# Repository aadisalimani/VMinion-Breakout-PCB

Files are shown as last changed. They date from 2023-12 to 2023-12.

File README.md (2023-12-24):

# VMinion Breakout PCB

This project is focused on creating a PCB that simplifies connections on the Ratrig VMinion. Although designed be me, it is inspired by the divider PCB mod by Vector3D [here](https://github.com/AdamV3D/RR-V-Minion-Mods/tree/main/V3D%20Divider%20PCB). 

## :warning: Beta Version :warning:
Please note that the "VMinion Breakout PCB" is currently in a **beta phase**. It's constantly being updated and improved. Use this mod at your own risk. The rest of the parts (printed casing, mounting parts, etc.) will come soon.

## Open Source
Everything related to this project will be open-source. Contributions, suggestions, and improvements are always welcome.

## Bill of Materials (BOM)
A work-in-progress BOM is available [here](https://docs.google.com/spreadsheets/d/1l2unTY74QwLAbzYWbJA4JIBaFDDriVfRlH6mz4mGnKs/edit?usp=sharing).

## Getting Started
*Features*

Unlike other breakout boards, this has a plethora of ports to fit almost any configuration:

- 4x Motor Ports
- 5x General Ports (Endstop, Servo, Neopixel etc.)
- 1x Probe Port (5v or 24v with diode)
- 3x Fan Ports (Selectable Voltage) - Two Ports Share Selected Voltage
- 1x ADXL Port
- 2x Therm Ports
- 1x Hotend Port (Max ~120W)
- 1x Bed Port (Max ~180W)
- 1x 24v Step Down To 12v (K78L12-500R3)

Uses 2x 2x9 Microfit And 1x Plugable Terminal Block

*Instrucions will follow soon*

## PCB Images
Top
Bottom

## License
This PCB project is licensed under the Creative Commons Attribution-NonCommercial 4.0 International License - see the [LICENSE](LICENSE) file for details.

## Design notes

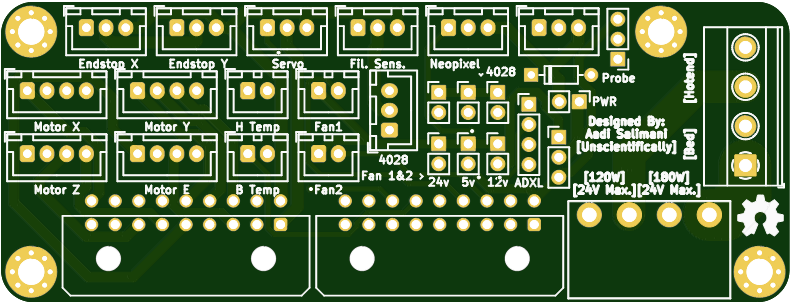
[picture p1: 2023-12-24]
Images/Top.png

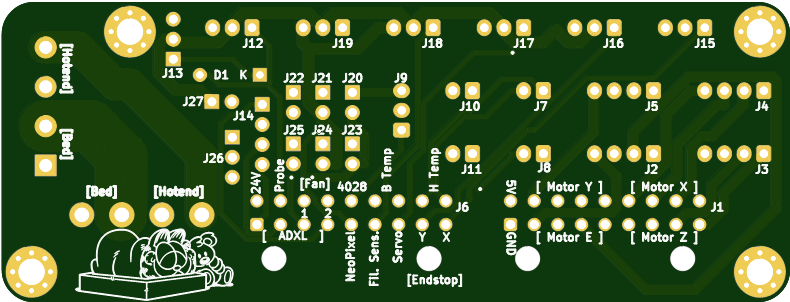
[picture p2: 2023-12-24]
Images/Bottom.png

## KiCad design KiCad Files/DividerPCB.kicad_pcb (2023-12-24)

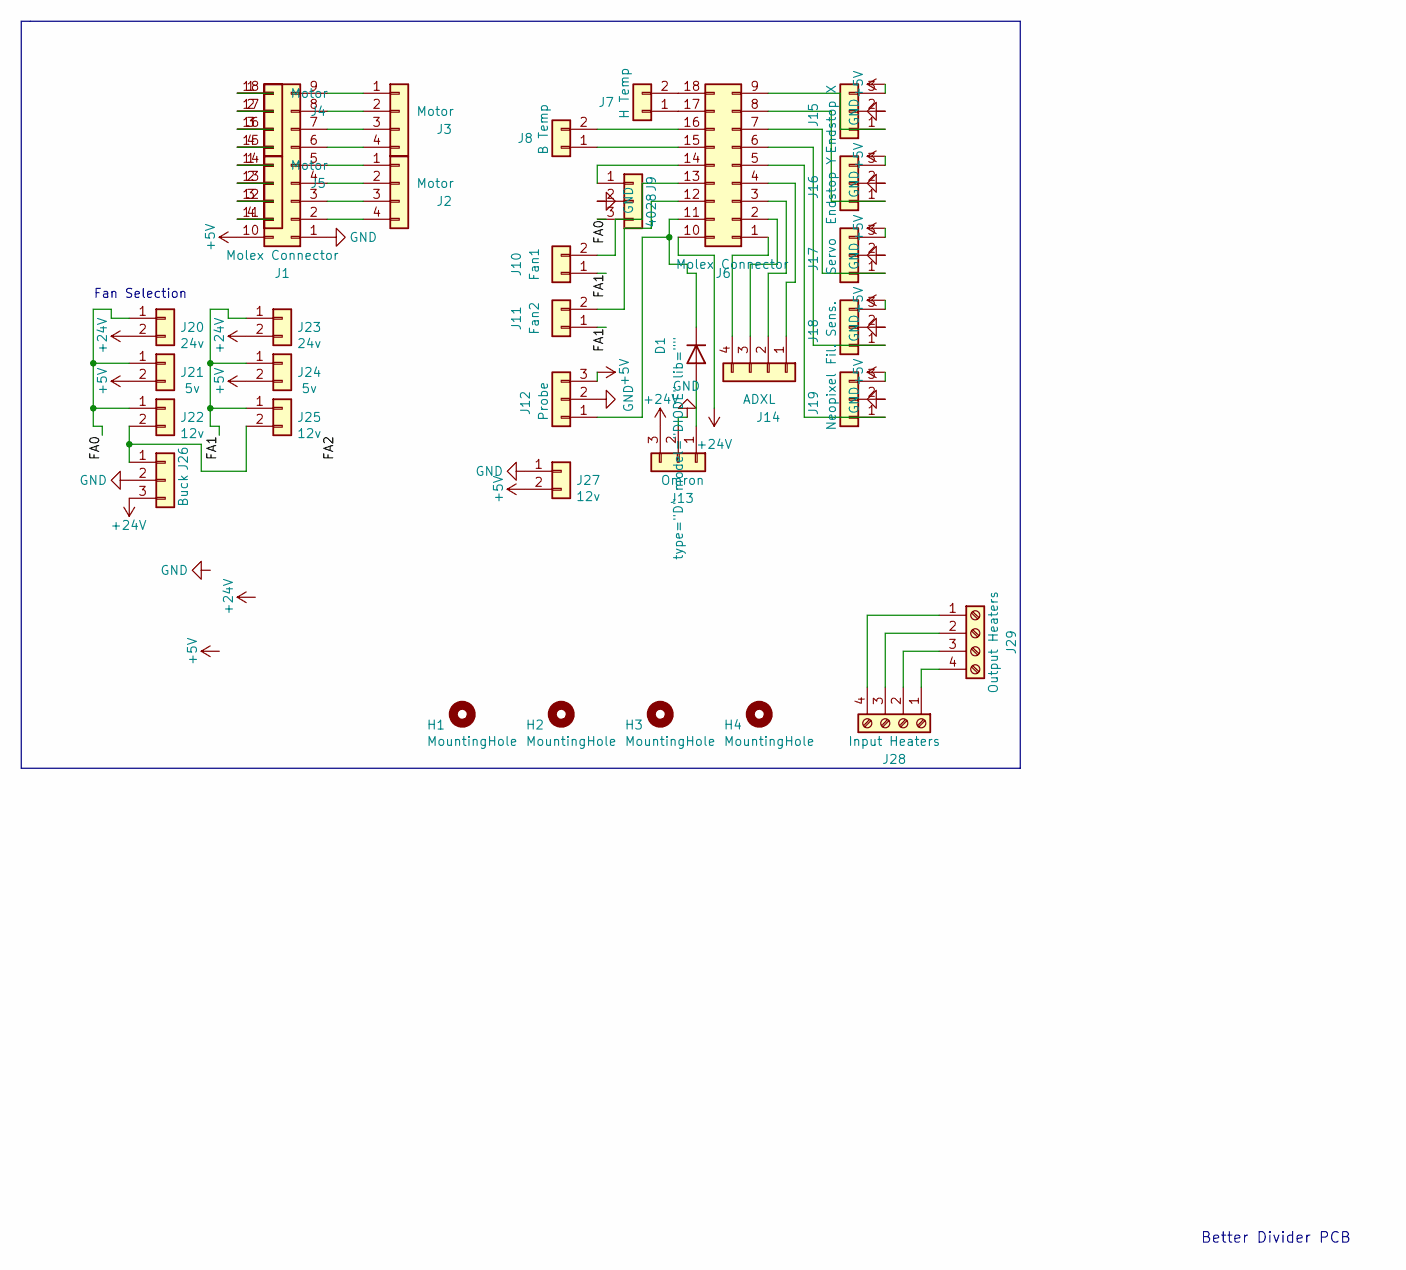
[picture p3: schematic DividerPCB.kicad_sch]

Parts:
D1: type="D" model="DIODE" lib=""; D_DO-35_SOD27_P7.62mm_Horizontal
H1, H2, H3, H4: MountingHole; MountingHole_3.2mm_M3_Pad_Via
J1, J6: Molex Connector; Molex_Micro-Fit_3.0_43045-1800_2x09_P3.00mm_Horizontal
J2, J3, J4, J5: Motor; JST_XH_B4B-XH-A_1x04_P2.50mm_Vertical
J7: H Temp; JST_XH_B2B-XH-A_1x02_P2.50mm_Vertical
J8: B Temp; JST_XH_B2B-XH-A_1x02_P2.50mm_Vertical
J9: 4028; JST_XH_B3B-XH-A_1x03_P2.50mm_Vertical
J10: Fan1; JST_XH_B2B-XH-A_1x02_P2.50mm_Vertical
J11: Fan2; JST_XH_B2B-XH-A_1x02_P2.50mm_Vertical
J12: Probe; JST_XH_B3B-XH-A_1x03_P2.50mm_Vertical
J13: Omron; PinHeader_1x03_P2.54mm_Vertical
J14: ADXL; PinHeader_1x04_P2.54mm_Vertical
J15: Endstop X; JST_XH_B3B-XH-A_1x03_P2.50mm_Vertical
J16: Endstop Y; JST_XH_B3B-XH-A_1x03_P2.50mm_Vertical
J17: Servo; JST_XH_B3B-XH-A_1x03_P2.50mm_Vertical
J18: Fil. Sens.; JST_XH_B3B-XH-A_1x03_P2.50mm_Vertical
J19: Neopixel; JST_XH_B3B-XH-A_1x03_P2.50mm_Vertical
J20, J23: 24v; PinHeader_1x02_P2.54mm_Vertical
J21, J24: 5v; PinHeader_1x02_P2.54mm_Vertical
J22, J25, J27: 12v; PinHeader_1x02_P2.54mm_Vertical
J26: Buck; PinHeader_1x03_P2.54mm_Vertical
J28: Input Heaters; 2EDGR-5.0-04P-14-00AH_DEG
J29: Output Heaters; TerminalBlock_Phoenix_MKDS-1,5-4_1x04_P5.00mm_Horizontal_Mod

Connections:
+5V: J1.10, J12.3, J15.3, J16.3, J17.3, J18.3, J19.3, J21.2, J24.2, J27.2
+24V: J6.10, J13.3, J20.2, J23.2, J26.3
/FA0: J9.3, J20.1, J21.1, J22.1
/FA1: J10.1, J11.1, J23.1, J24.1, J25.1
GND: J1.1, J9.2, J12.2, J13.2, J15.2, J16.2, J17.2, J18.2, J19.2, J26.2, J27.1
unnamed: D1.1 (A), J13.1
unnamed: D1.2 (K), J6.11, J12.1
unnamed: J1.2, J2.4
unnamed: J1.3, J2.3
unnamed: J1.4, J2.2
unnamed: J1.5, J2.1
unnamed: J1.6, J3.4
unnamed: J1.7, J3.3
unnamed: J1.8, J3.2
unnamed: J1.9, J3.1
unnamed: J1.11, J5.4
unnamed: J1.12, J5.3
unnamed: J1.13, J5.2
unnamed: J1.14, J5.1
unnamed: J1.15, J4.4
unnamed: J1.16, J4.3
unnamed: J1.17, J4.2
unnamed: J1.18, J4.1
unnamed: J6.14, J9.1
unnamed: J6.15, J8.1
unnamed: J6.16, J8.2
unnamed: J6.17, J7.1
unnamed: J6.18, J7.2
unnamed: J6.13, J10.2
unnamed: J6.12, J11.2
unnamed: J6.4, J14.1
unnamed: J6.3, J14.2
unnamed: J6.2, J14.3
unnamed: J6.1, J14.4
unnamed: J6.9, J15.1
unnamed: J6.8, J16.1
unnamed: J6.7, J17.1
unnamed: J6.6, J18.1
unnamed: J6.5, J19.1
unnamed: J22.2, J25.2, J26.1
unnamed: J28.1, J29.4
unnamed: J28.2, J29.3
unnamed: J28.3, J29.2
unnamed: J28.4, J29.1

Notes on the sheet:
Fan Selection
Better Divider PCB

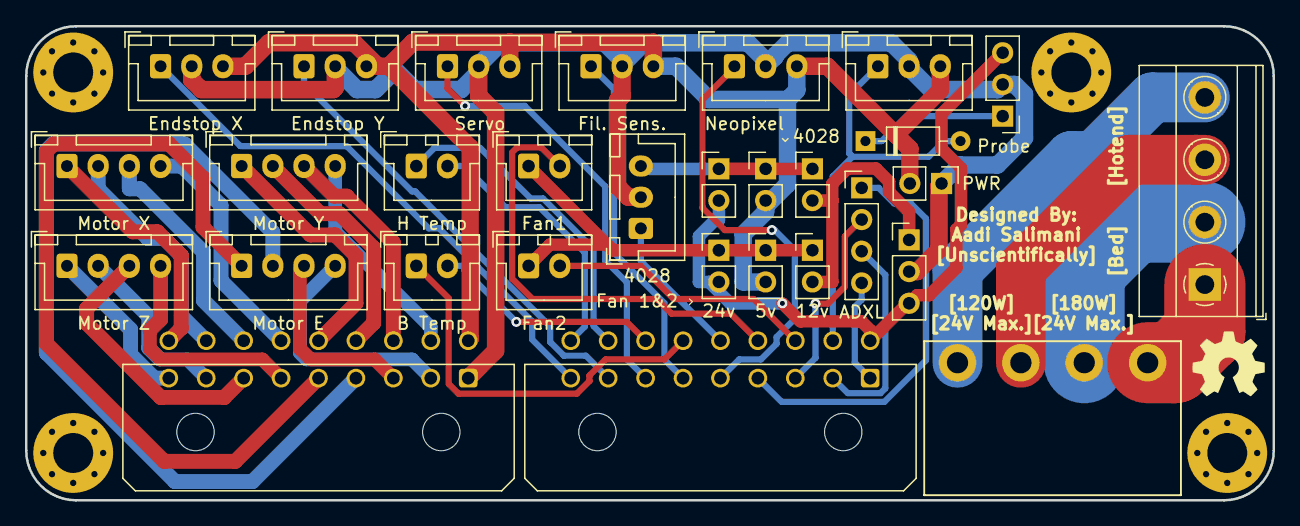
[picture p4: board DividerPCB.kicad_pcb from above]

Board: 2 copper layers, 100.0 x 38.0 mm, 36 parts (1 on the bottom side), 44 nets.

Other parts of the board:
Garfield: LOGO; sleeping
Open: LOGO; open

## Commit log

2023-11-23 Create KiCad Stuff
2023-11-23 Update KiCad Stuff
